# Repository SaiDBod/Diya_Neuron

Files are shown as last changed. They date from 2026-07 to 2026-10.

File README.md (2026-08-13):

# Diya
Light illumination device for cells cultured in multiwell plates or culture dishes

## hardware
- CAD files for hardware designs
- More_CAD contains files for Adafruit 64x64 P3 board and a container for the controller
- Assembly instructions

## software
- Source code for Diya GUI
- See Output Folder for Windows Installer
- Diya_Neuron_Installer is Inno Setup file for the creation of the Installer

## Advanced - Modification Descriptions
- Added this to Line 354 - 355 of mainWidget.py while changing subsequent lines:
    - self.StepGBoxes[step_nr][6].setDecimals(2)
    - self.StepGBoxes[step_nr][6].setSingleStep(0.02)
    - self.StepGBoxes[step_nr][6].setSuffix(' sec')
    - self.StepGBoxes[step_nr][6].setMaximum(59.99)
- Line 333 of mainWidget.py changed to:  QSpinBox(), QSpinBox(), QDoubleSpinBox(),
- framerate (limiting factor) on line 47 of setup.py was changed to 1/3000 for 20 ms times
- Line 401 of makegif.py changed from fps=10 to fps=50 (20 ms times)

## Other Notes
- The exported GIFs only make frames every 20 ms, so steps at 0.01, 0.03, 0.05... seconds may not work as intended
- 10 ms frame times do not work with HUIDU technology/ software (hard limit seems to be at 60 FPS, but only 50 FPS was tested)

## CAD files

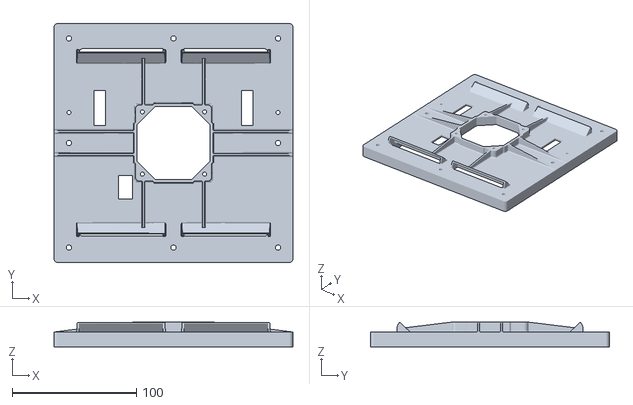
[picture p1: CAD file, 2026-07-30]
hardware/CAD_files/back_plate/back_plate_complete.stl
192.0 x 192.0 x 20.0

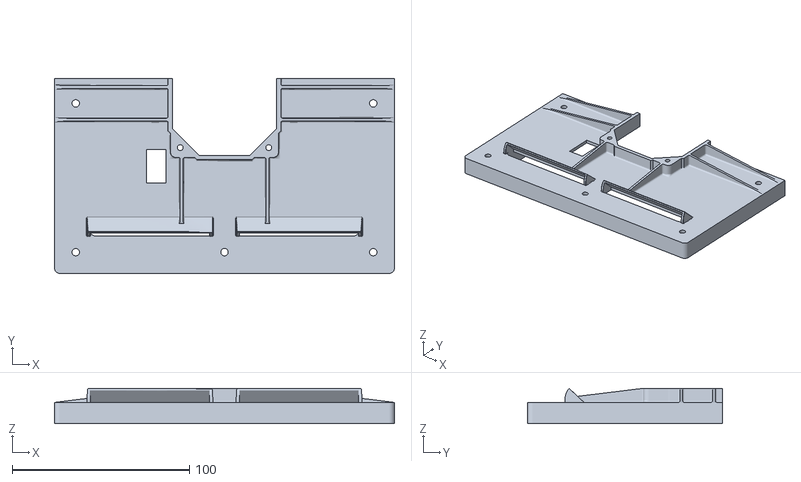
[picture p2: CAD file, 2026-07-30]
hardware/CAD_files/back_plate/back_plate_part2.stl
192.0 x 110.0 x 20.0

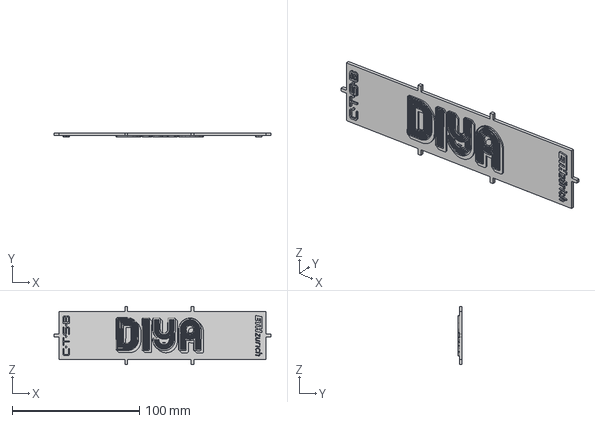
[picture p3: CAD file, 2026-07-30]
hardware/CAD_files/diya_logo/diya_ctsb_eth_logo.step
170.6 x 3.00 x 45.6 mm

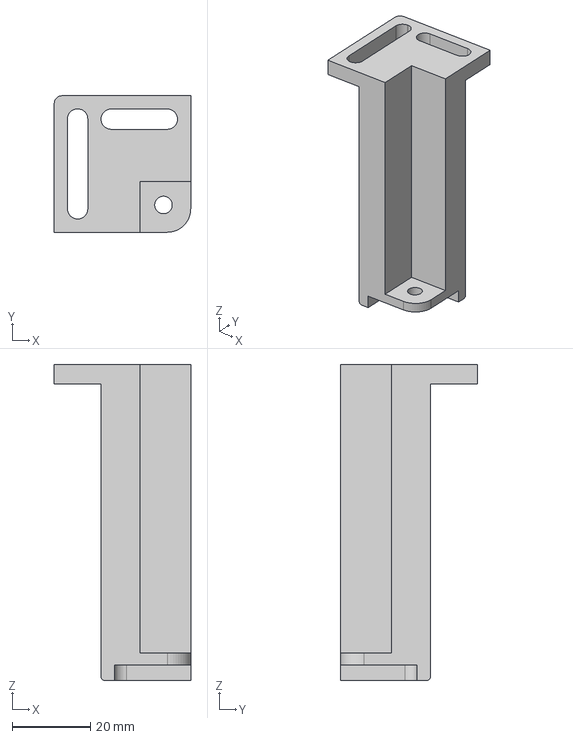
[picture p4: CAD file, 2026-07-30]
hardware/CAD_files/stands/stands.step
35.0 x 35.0 x 81.0 mm

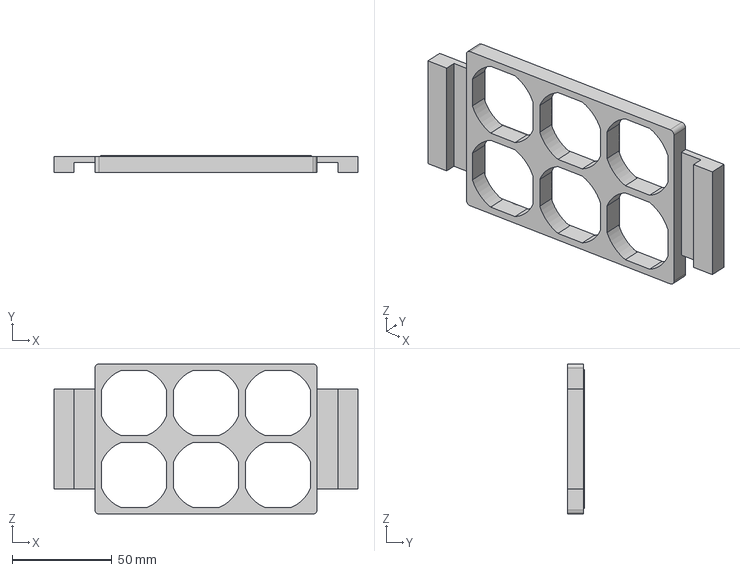
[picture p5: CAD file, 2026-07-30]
hardware/CAD_files/well_plate_adapters/6_well_plate_adapter.step
152.0 x 8.50 x 75.0 mm

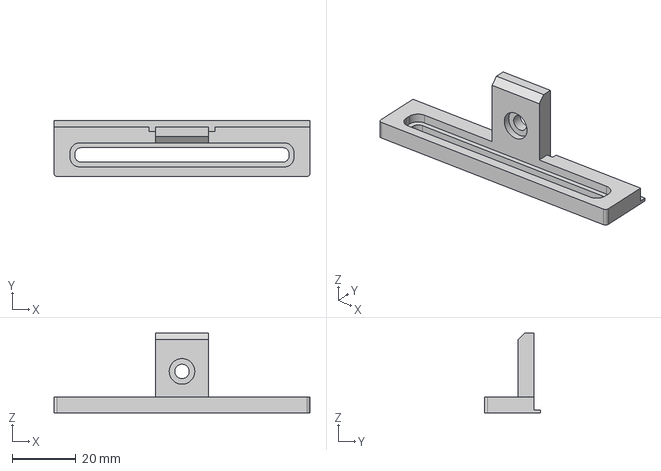
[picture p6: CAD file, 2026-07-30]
hardware/CAD_files/well_plate_clamper/side_clamps.step
80.0 x 17.5 x 25.0 mm

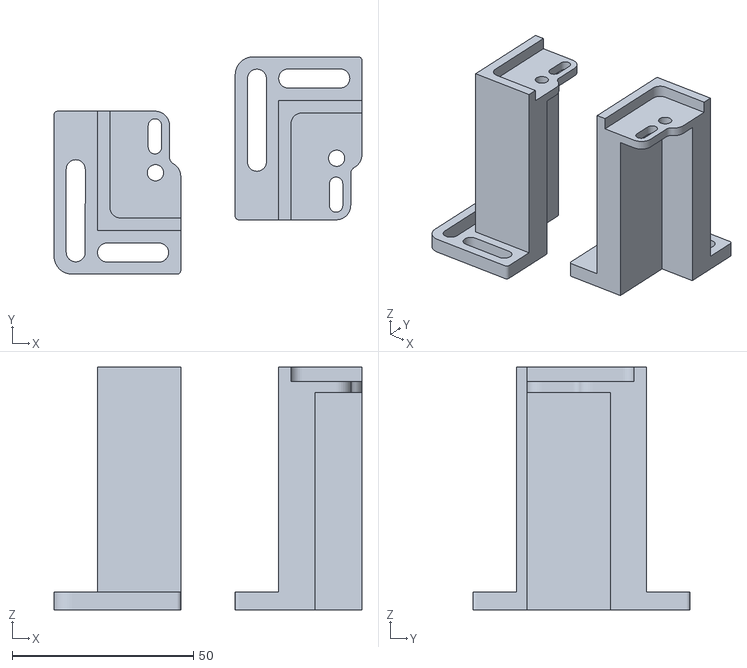
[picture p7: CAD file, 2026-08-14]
More_CAD/Stands_ReImagined2.stl
85.0 x 60.0 x 67.0

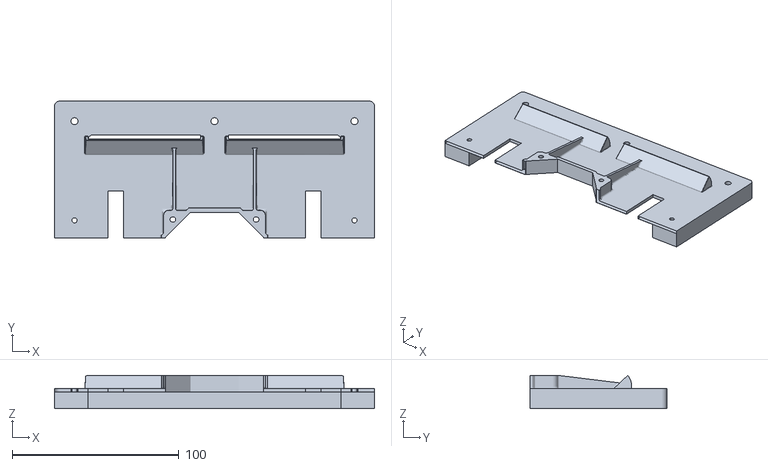
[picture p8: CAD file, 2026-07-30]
hardware/CAD_files/back_plate/back_plate_part1.stl
192.0 x 82.0 x 20.0

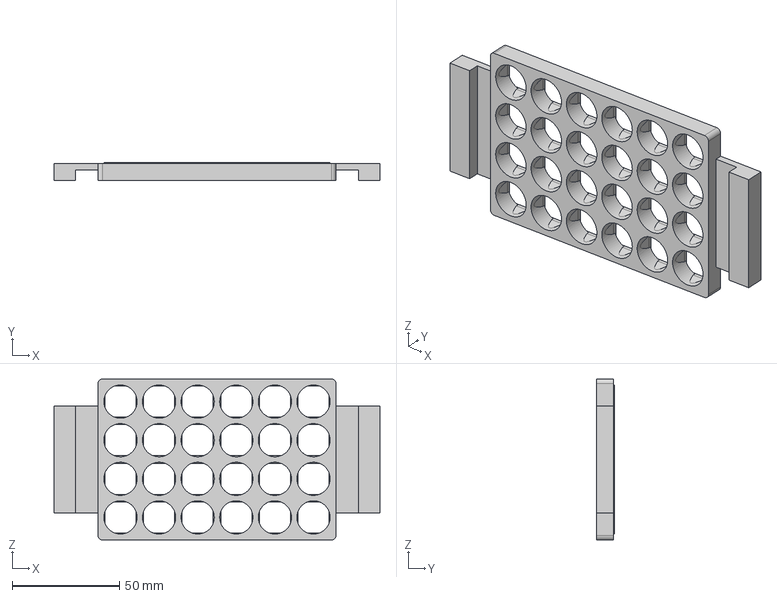
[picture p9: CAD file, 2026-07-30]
hardware/CAD_files/well_plate_adapters/24_well_plate_adapter.step
152.0 x 8.50 x 75.0 mm

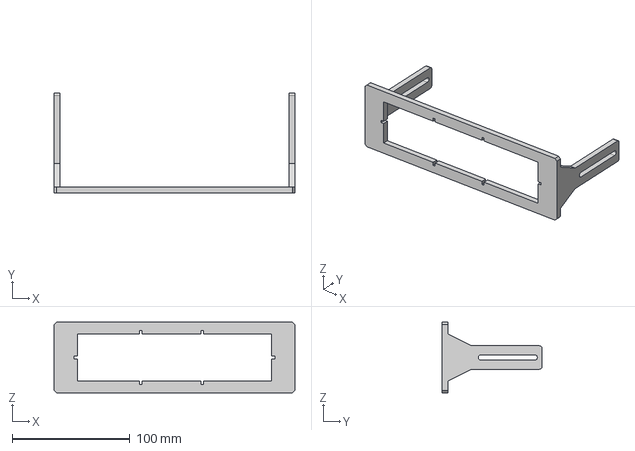
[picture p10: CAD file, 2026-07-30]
hardware/CAD_files/well_plate_clamper/well_plate_clamper.step
205.0 x 85.0 x 60.0 mm

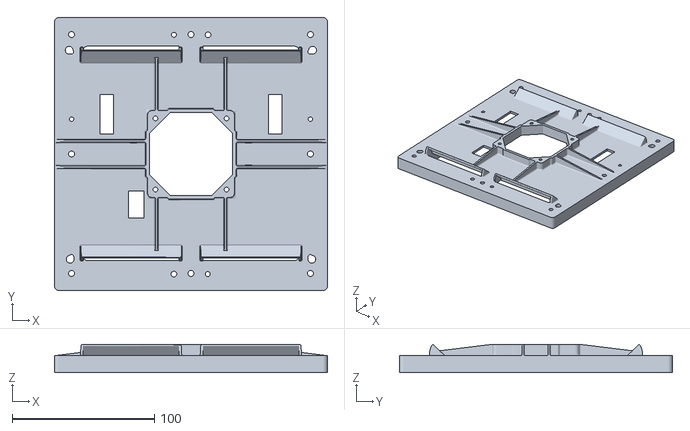
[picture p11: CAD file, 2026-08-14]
More_CAD/BackPlate_ReImagined5.stl
192.0 x 192.0 x 20.0

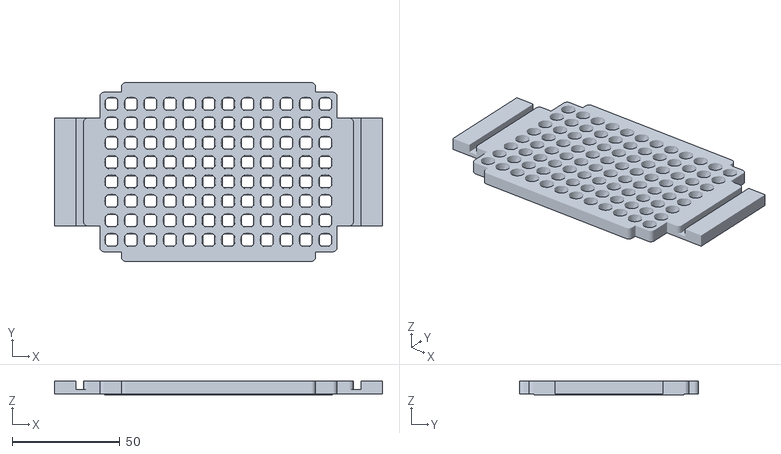
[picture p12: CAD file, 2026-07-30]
hardware/CAD_files/well_plate_adapters/96_U_bottom_adapter.stl
152.0 x 82.9 x 6.50

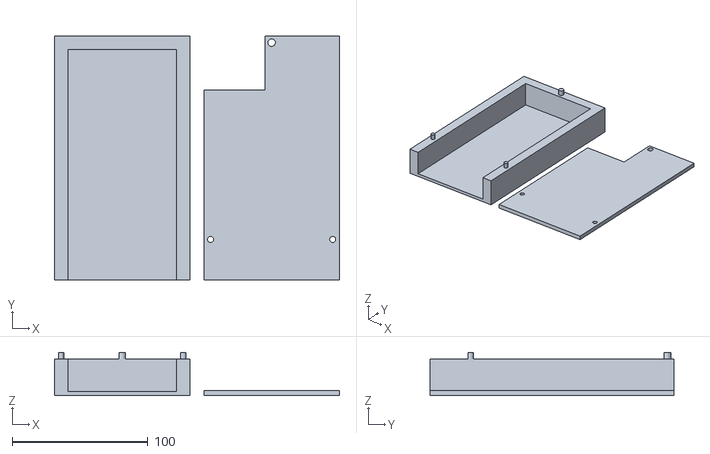
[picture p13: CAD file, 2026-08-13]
More_CAD/Huidu_Holder2.stl
210.0 x 180.0 x 32.0

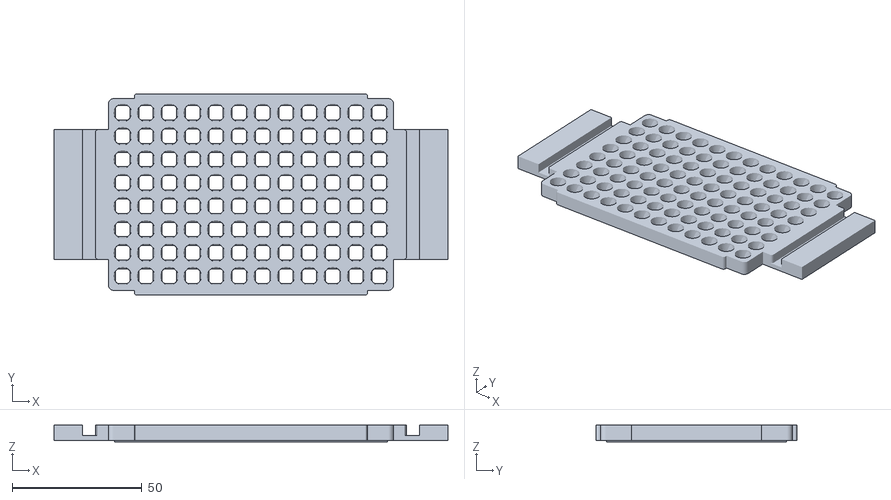
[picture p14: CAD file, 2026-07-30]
hardware/CAD_files/well_plate_adapters/96_well_plate_adapter.stl
152.0 x 77.6 x 6.50

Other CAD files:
hardware/CAD_files/diya_logo/diya_ctsb_eth_logo.stl
hardware/CAD_files/stands/stands.stl
hardware/CAD_files/well_plate_adapters/24_well_plate_adapter.stl
hardware/CAD_files/well_plate_adapters/6_well_plate_adapter.stl
hardware/CAD_files/well_plate_clamper/side_clamps.stl
hardware/CAD_files/well_plate_clamper/well_plate_clamper.stl

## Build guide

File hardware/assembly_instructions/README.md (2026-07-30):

This pdf contains step-by-step intructions for assembling a Diya device. The instructions assume that you have acquired and 3D printed all the parts needed for the assembly. Please refer to the paper for more details.

* Parts list is provided in the paper supplimentary information.
* CAD files for 3D printing are available in the hardware > CAD_files folder (in this repository).

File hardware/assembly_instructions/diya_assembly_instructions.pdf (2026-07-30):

## Step 0

- Acquire all parts (check parts list provided in the paper supplementary information) needed for assembling one Diya device
- Print the required 3D printed parts (check hardware > CAD_files folder)
- A set of screw drivers is needed in the assembly process

## Step 1

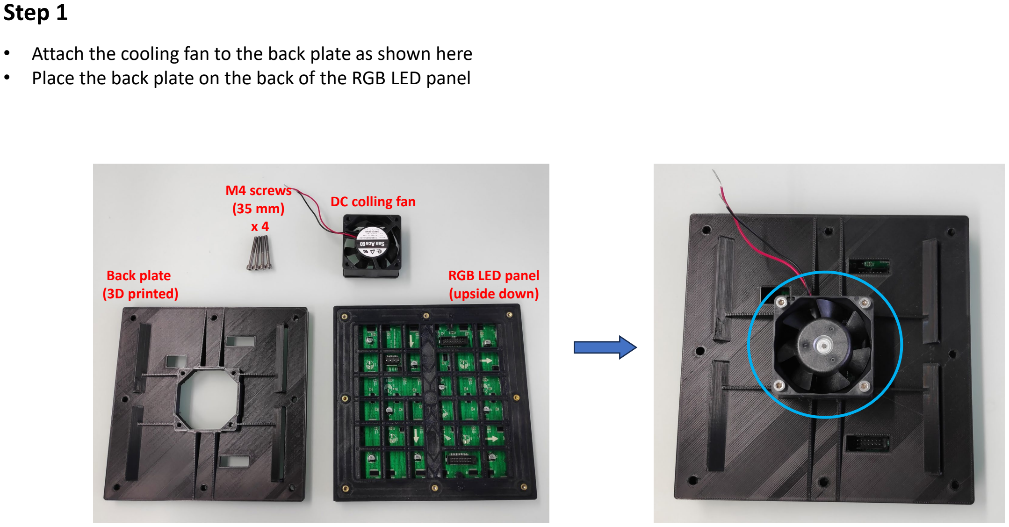
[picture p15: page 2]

- Attach the cooling fan to the back plate as shown here
- Place the back plate on the back of the RGB LED panel

Back plate
(3D printed)

RGB LED panel
(upside down)

M4 screws
(35 mm)
x 4

DC colling fan

## Step 2

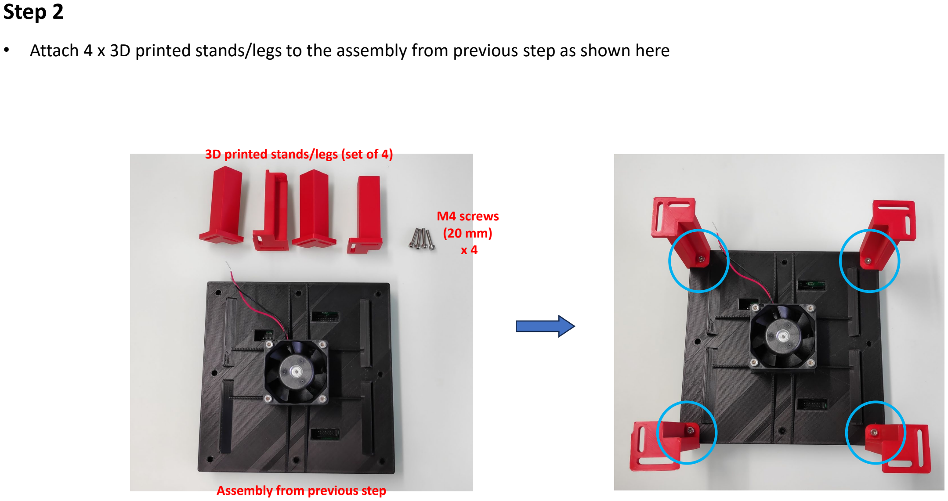
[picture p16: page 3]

- Attach 4 x 3D printed stands/legs to the assembly from previous step as shown here

Assembly from previous step

3D printed stands/legs (set of 4)

M4 screws
(20 mm)
x 4

## Step 3

- Attach 2 x 3D printed side clamps to the assembly from previous step as shown here

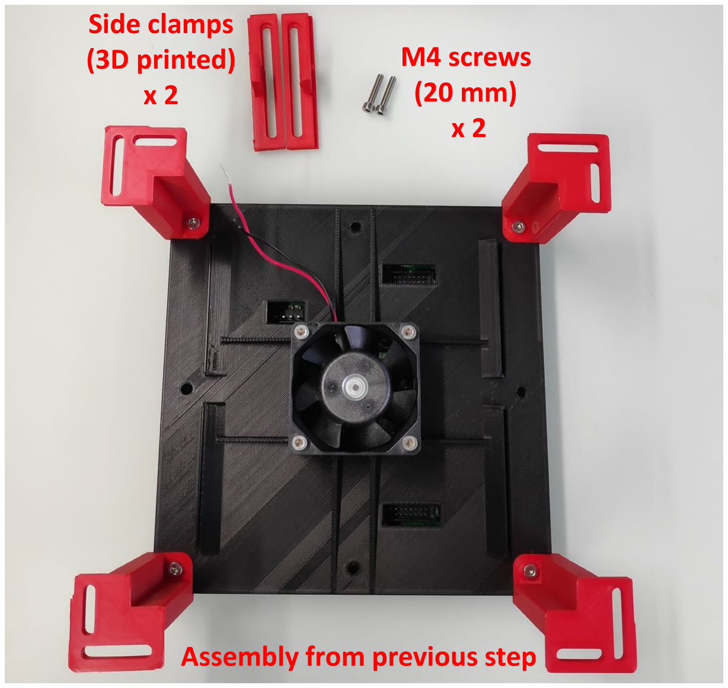
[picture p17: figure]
Assembly from previous step; Side clamps (3D printed) x 2; M4 screws (20 mm) x 2
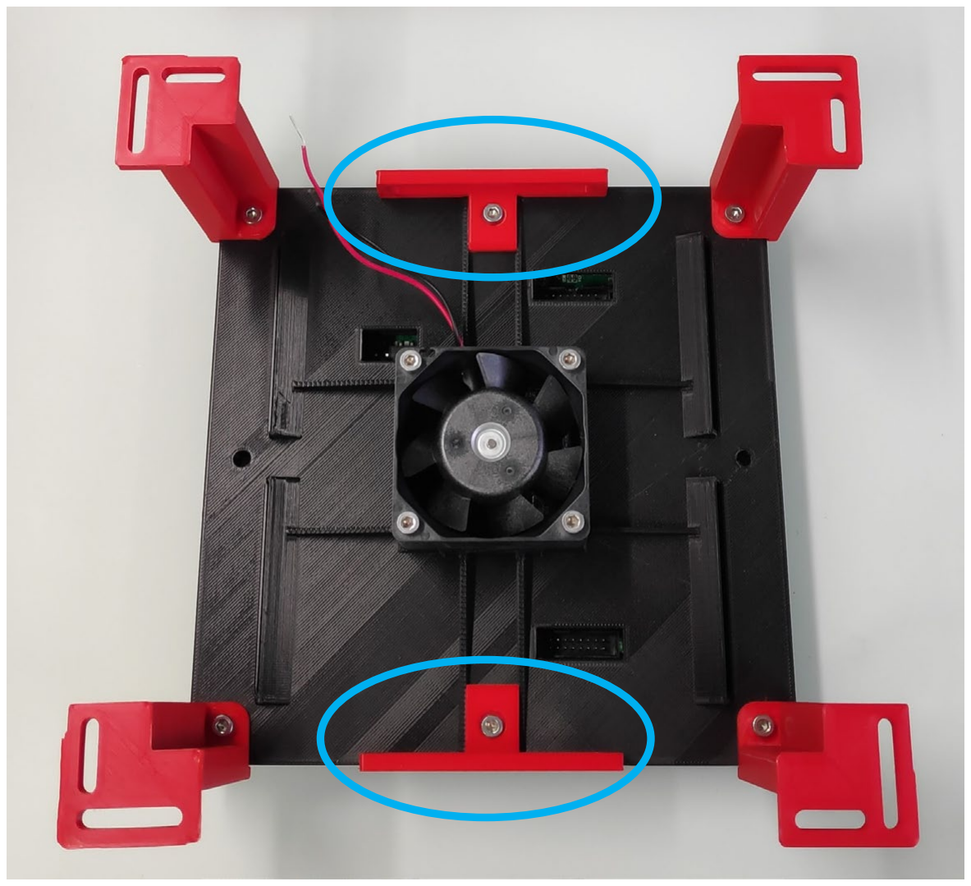
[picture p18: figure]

## Step 4

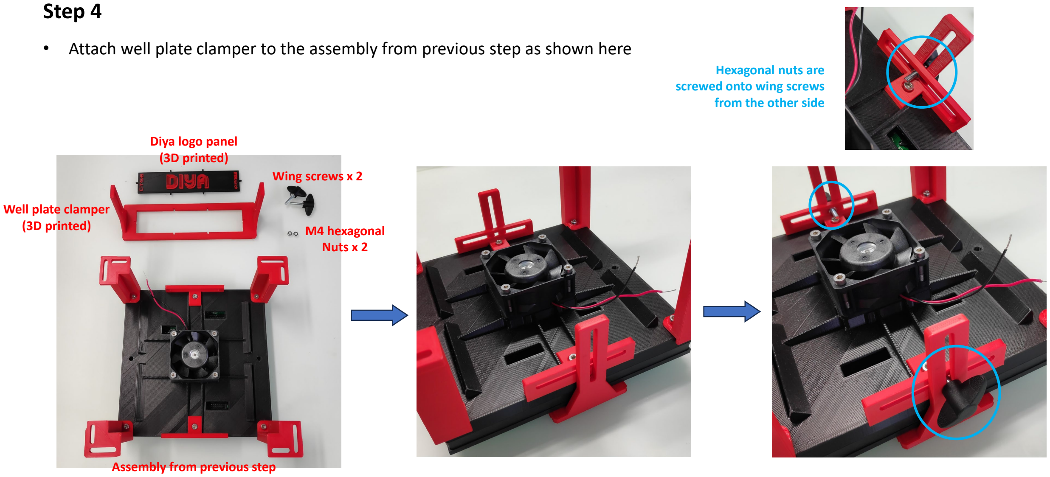
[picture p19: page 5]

- Attach well plate clamper to the assembly from previous step as shown here

Assembly from previous step

Well plate clamper
(3D printed)

Diya logo panel
(3D printed)
Wing screws x 2

M4 hexagonal
Nuts x 2

Hexagonal nuts are
screwed onto wing screws
from the other side

## Step 5 (Optional)

- Attach Diya logo panel to the well plate clamper as shown here
- Glue can be used to firmly attach the logo panel in place

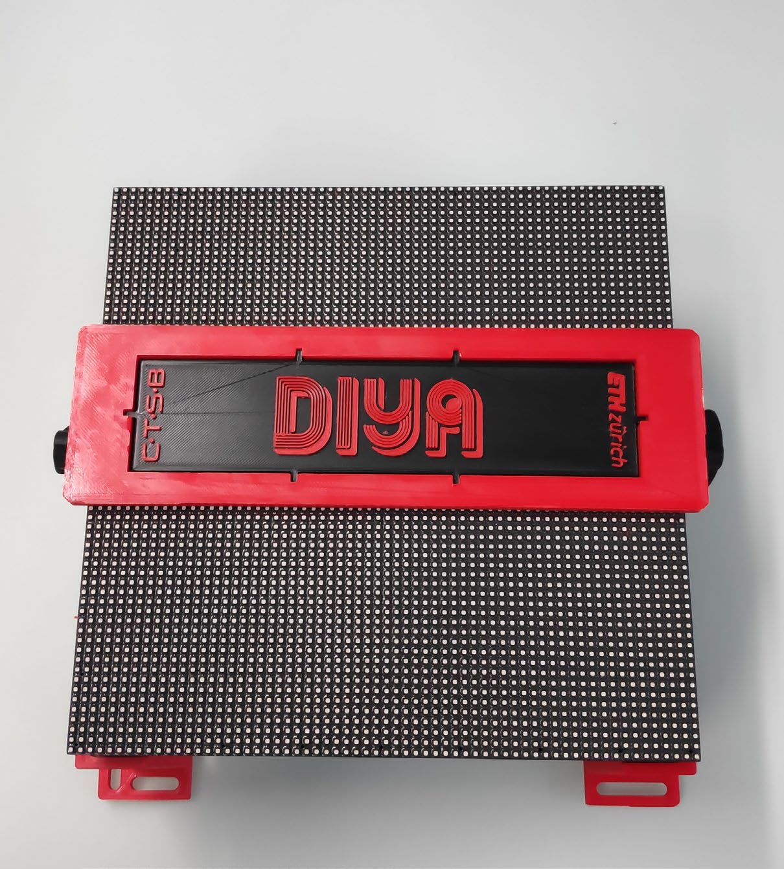
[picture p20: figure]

## Step 6

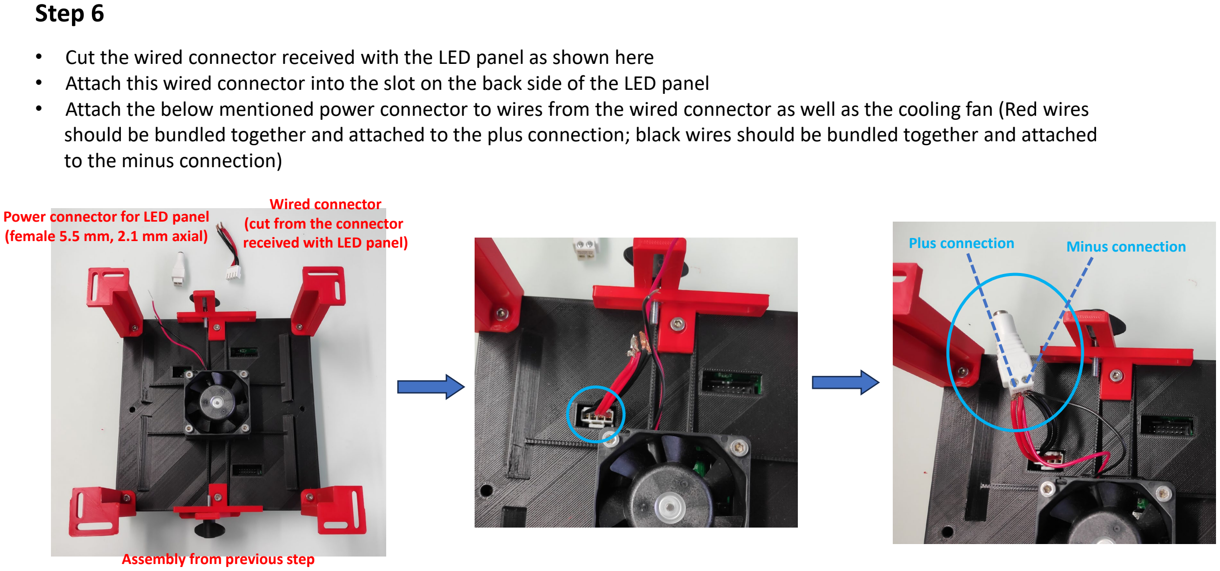
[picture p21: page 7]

- Cut the wired connector received with the LED panel as shown here
- Attach this wired connector into the slot on the back side of the LED panel
- Attach the below mentioned power connector to wires from the wired connector as well as the cooling fan (Red wires should be bundled together and attached to the plus connection; black wires should be bundled together and attached to the minus connection)

Assembly from previous step

Power connector for LED panel (female 5.5 mm, 2.1 mm axial)

Wired connector
(cut from the connector
received with LED panel) | Plus connection | Minus connection

## Step 7

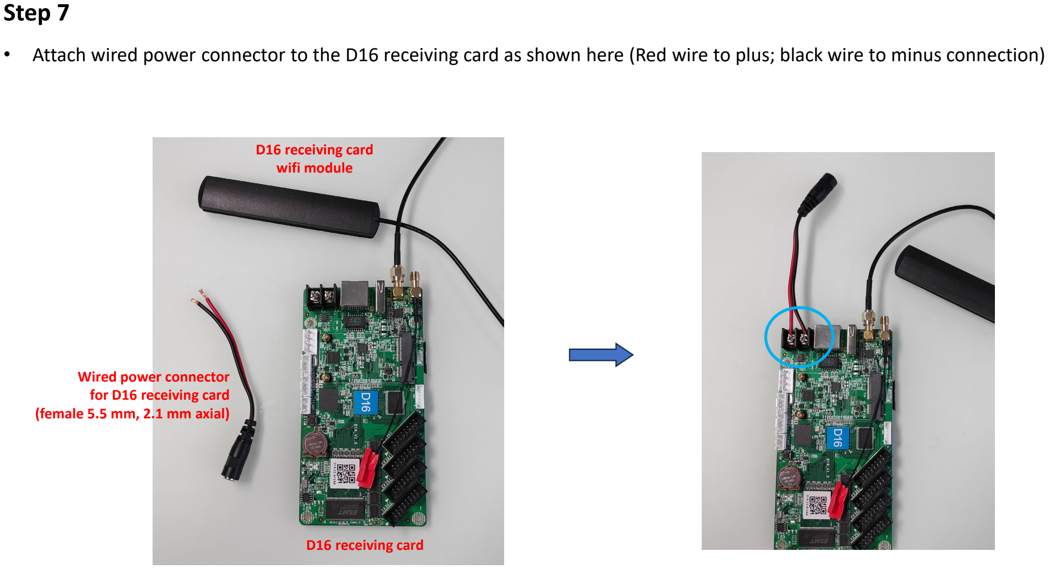
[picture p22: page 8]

- Attach wired power connector to the D16 receiving card as shown here (Red wire to plus; black wire to minus connection)

Wired power connector
for D16 receiving card
(female 5.5 mm, 2.1 mm axial)

D16 receiving card
wifi module

D16 receiving card

## Step 8

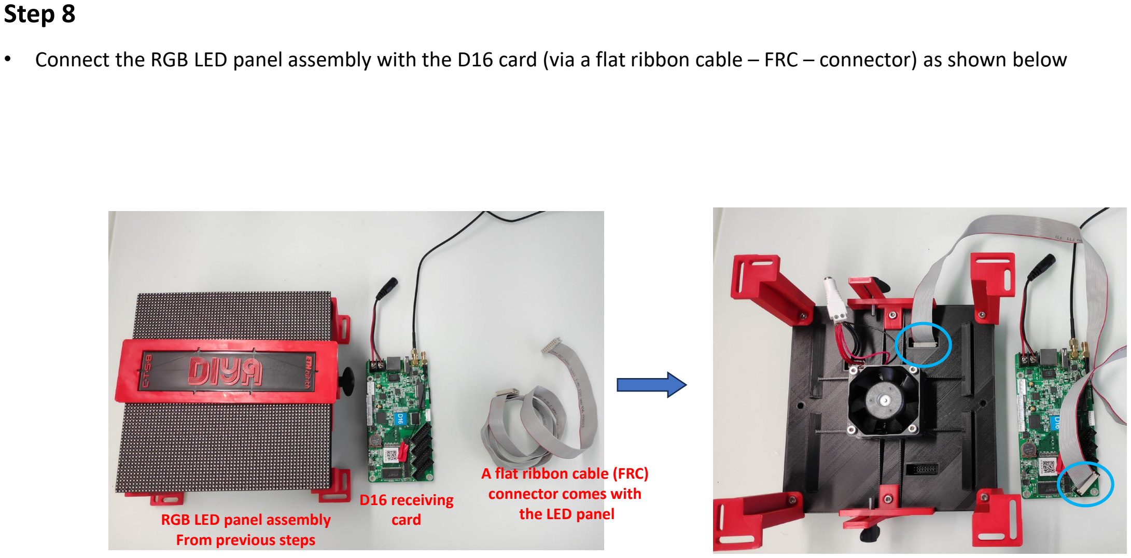
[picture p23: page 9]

- Connect the RGB LED panel assembly with the D16 card (via a flat ribbon cable – FRC – connector) as shown below

RGB LED panel assembly
From previous steps

A flat ribbon cable (FRC)
connector comes with
the LED panel D16 receiving card

## Step 9

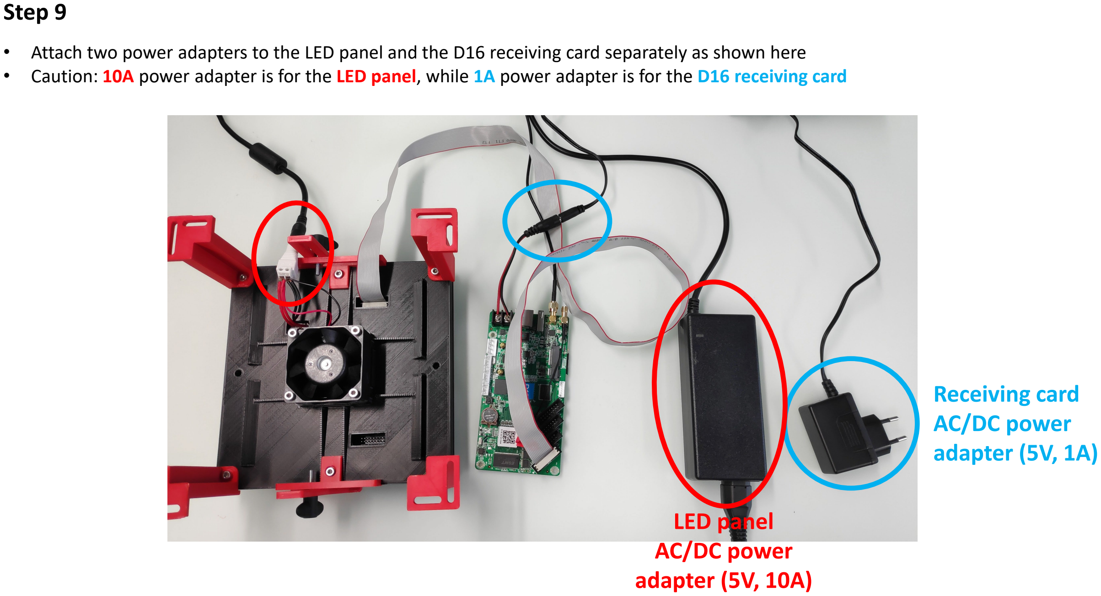
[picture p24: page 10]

- Attach two power adapters to the LED panel and the D16 receiving card separately as shown here
- Caution: 10A power adapter is for the LED panel, while 1A power adapter is for the D16 receiving card

## Receiving card AC/DC power adapter (5V, 1A)

## LED panel AC/DC power adapter (5V, 10A)

## Step 10

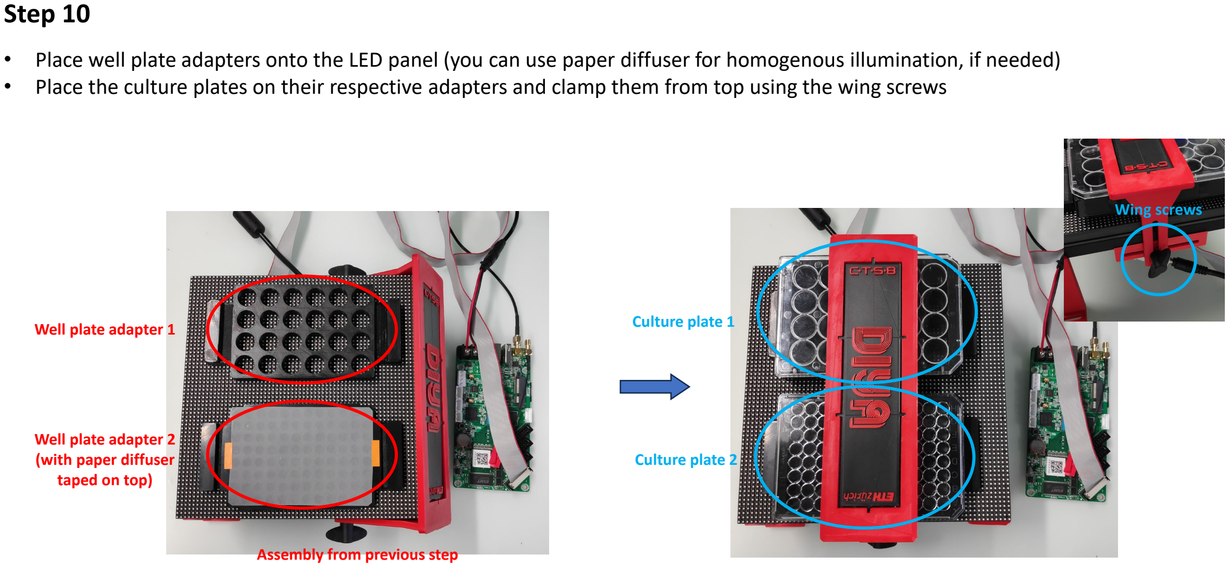
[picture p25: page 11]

- Place well plate adapters onto the LED panel (you can use paper diffuser for homogenous illumination, if needed)
- Place the culture plates on their respective adapters and clamp them from top using the wing screws

Well plate adapter 1

Well plate adapter 2
(with paper diffuser
taped on top)

Assembly from previous step

Wing screws

Culture plate 1

Culture plate 2

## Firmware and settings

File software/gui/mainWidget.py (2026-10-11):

from PyQt5.QtWidgets import *
from PyQt5.QtGui import * 
from PyQt5.QtCore import *

from pyqtgraph import PlotWidget, plot
import pyqtgraph as pg

import ast
import os

import numpy as np
from math import sqrt

from wellInforamtion import wellInfoWindow

basedir = os.path.dirname(__file__)

class well_buttons(QWidget):#
    #Creation of widgets
    def __init__(self, framerate):
        super().__init__()

        self.plate_type = 96
        self.plate_nr = 0

        self.plate_nr_type = {0: 96, 1: 96}

        self.plate_width = 8
        self.plate_height = 12
        self.well_button_size = 30
        self.well_button_radius = 15

        self.color = 'Off'
        self.wvMax = 255
        self.wvMin = 0
        self.wvStart = 'Low'
        self.wvLen = 20
        self.dutyCyclePWM = 0.5
        self.periodPWM = 20

        self.framerate = framerate

        self.StepGBoxes = {}
        self.StepInformations = {}
        self.amount_of_steps = 1
        self.selceted_step = 1

        self.ButtonNrTL = 1
        self.selected_wells = set()
        self.used_wells_plate_1 = {}
        self.used_wells_plate_2 = {}
        self.Button_to_pos = {}
        self.Pos_to_Button = {}

        self.plotPreviewDisplayed = False
        self.wellInfoWin = None
        
        self.setWindowTitle('opto GUI')
        self.createPlotPreview(10)
        self.createPlateChooserBox()
        self.createCurrentStepBox()
        self.createProgrammBox()
        self.createActions()
        self.createContextMenu()
        
        self.selectWellsRB.setChecked(True)

        self.graphProgrammStack = QStackedWidget(self)
        self.graphProgrammStack.addWidget(self.ProgrammGBox)
        self.graphProgrammStack.addWidget(self.graphWidget)

        Programm_HLayout = QVBoxLayout()
        Programm_HLayout.addWidget(self.PlateChooserBox)
        Programm_HLayout.addWidget(self.graphProgrammStack)

        self.mainLayout = QHBoxLayout()
        self.mainLayout.addLayout(Programm_HLayout)
        self.mainLayout.addWidget(self.CurrentStepGBox)
        self.setLayout(self.mainLayout)

    def createwellButtonBox(self):

        self.wellButtonBox = QGroupBox("Select wells")
        wells_layout = QGridLayout()

        rows_per_plate, cols_per_plate = self.plate_height, self.plate_width

        self.select_buttons = {}
        self.well_buttons = {}
        self.Button_to_pos = {}
        self.Pos_to_Button = {}

        self.select_all_button = QPushButton('All', self)
        self.select_all_button.\
         setStyleSheet("border-radius : {radius}; border: 1px solid black;".format(radius = 15))
        self.select_all_button.setFixedSize(30, 30)
        self.select_all_button.clicked.connect(self.select_all)
        wells_layout.addWidget(self.select_all_button, 0, 0, alignment = Qt.AlignCenter)

        for col in range(cols_per_plate):
            col_nr = col + 1
            self.select_buttons['Button_C' + str(col_nr)] = QPushButton('', self)
            self.select_buttons['Button_C' + str(col_nr)].\
             setStyleSheet("border-radius : {radius}; border: 1px solid black;".format(radius = 15))
            self.select_buttons['Button_C' + str(col_nr)].setIcon(QIcon(os.path.join(basedir, 'resources', 'arrow-down.svg')))
            self.select_buttons['Button_C' + str(col_nr)].setFixedSize(30, 30)
            self.select_buttons['Button_C' + str(col_nr)].clicked.connect(lambda ignore, i=col_nr: self.select_col(i))
            wells_layout.addWidget(self.select_buttons['Button_C' + str(col_nr)], 0, col + 1, alignment = Qt.AlignCenter)

        for row in range(rows_per_plate):
            row_nr = row + 1
            self.select_buttons['Button_R' + str(row_nr)] = QPushButton('', self)
            self.select_buttons['Button_R' + str(row_nr)].\
             setStyleSheet("border-radius : {radius}; border: 1px solid black;".format(radius = 15))
            self.select_buttons['Button_R' + str(row_nr)].setIcon(QIcon(os.path.join(basedir, 'resources', 'arrow-right.svg')))
            self.select_buttons['Button_R' + str(row_nr)].setFixedSize(30, 30)
            self.select_buttons['Button_R' + str(row_nr)].clicked.connect(lambda ignore, i=row_nr: self.select_row(i))
            wells_layout.addWidget(self.select_buttons['Button_R' + str(row_nr)], row + 1, 0, alignment = Qt.AlignCenter)

        for x in range(cols_per_plate):
            for y in range(rows_per_plate):
                button_nr = x+y*cols_per_plate+1
                self.well_buttons['Button_' + str(button_nr)] = QPushButton('', self)
                self.Button_to_pos['Button_' + str(button_nr)] = (y, x)
                self.well_buttons['Button_' + str(button_nr)].\
                 setStyleSheet("border-radius : {radius}; border: 1px solid black;".format(radius = self.well_button_radius))
                self.well_buttons['Button_' + str(button_nr)].setFixedSize(self.well_button_size, self.well_button_size)
                self.well_buttons['Button_' + str(button_nr)].clicked.connect(lambda ignore, i=button_nr: self.select_wells(i))
                self.well_buttons['Button_' + str(button_nr)].setContextMenuPolicy(Qt.CustomContextMenu)
                self.well_buttons['Button_' + str(button_nr)].customContextMenuRequested.connect(lambda point, i=button_nr: self.showWellContextMenu(i, point))
                wells_layout.addWidget(self.well_buttons['Button_' + str(button_nr)], y+1, x+1)
        self.wellButtonBox.setLayout(wells_layout)
        self.Pos_to_Button = {y: x for x, y in self.Button_to_pos.items()}

    def createPlateChooserBox(self):
        self.PlateChooserBox = QGroupBox("Choose Plate")
        chooserForm_layout = QFormLayout()

        self.plate_chooser_CB = QComboBox()
        self.plate_chooser_CB.addItem("Plate 1")
        self.plate_chooser_CB.addItem("Plate 2")
        self.plate_chooser_CB.addItem("---")

        self.plate_chooser_CBView = self.plate_chooser_CB.view()
        self.plate_chooser_CBView.setRowHidden(2, True)

        self.plate_chooser_CB.currentIndexChanged.connect(self.changePlate)

        self.plate_type_CB = QComboBox()
        self.plate_type_CB.addItem("96-well Plate")
        self.plate_type_CB.addItem("24-well Plate")
        self.plate_type_CB.addItem("6-well Plate")
        self.plate_type_CB.addItem("Custom Shape")

        self.plate_type_CBView = self.plate_type_CB.view()
        self.plate_type_CBView.setRowHidden(3, True)

        self.plate_type_CB.currentIndexChanged.connect(self.changePlateType)

        self.duplicate_plate_button = QPushButton('Duplicate Plate', self)
        self.duplicate_plate_button.clicked.connect(self.duplicate_plate)

        chooserForm_layout.addRow(QLabel('Choose Plate'), self.plate_chooser_CB)
        chooserForm_layout.addRow(QLabel('Choose Plate Type'), self.plate_type_CB)
        chooserForm_layout.addRow(QLabel(''), self.duplicate_plate_button)

        self.PlateChooserBox.setLayout(chooserForm_layout)

    def createParameterBox(self):
        self.ParameterBox = QGroupBox("Animate wells")
        self.ParameterFormlayout = QFormLayout()

        self.color_chooser = QComboBox()
        self.color_chooser.addItem("Off")
        self.color_chooser.addItem("Red")
        self.color_chooser.addItem("Green")
        self.color_chooser.addItem("Blue")
        self.color_chooser.addItem("Multicolor")
        self.color_chooser.setCurrentText(self.color)
        self.color_chooser.currentIndexChanged.connect(self.changeWavetype)

        self.waveTypeCB = QComboBox()
        self.waveTypeCB.addItem("Constant")
        self.waveTypeCB.addItem("Sine Wave")
        self.waveTypeCB.addItem("Tri Wave")
        self.waveTypeCB.addItem("Square Wave")
        self.waveTypeCB.addItem("PWM")
        self.waveTypeCB.addItem("Rise")
        self.waveTypeCB.addItem("Fall")
        self.waveTypeCB.setItemIcon(0, QIcon(os.path.join(basedir, 'resources', 'animation-static.svg')))
        self.waveTypeCB.setItemIcon(1, QIcon(os.path.join(basedir, 'resources', 'animation-sin.svg')))
        self.waveTypeCB.setItemIcon(2, QIcon(os.path.join(basedir, 'resources', 'animation-tri.svg')))
        self.waveTypeCB.setItemIcon(3, QIcon(os.path.join(basedir, 'resources', 'animation-sq.svg')))
        self.waveTypeCB.setItemIcon(4, QIcon(os.path.join(basedir, 'resources', 'animation-blink.svg')))
        self.waveTypeCB.setItemIcon(5, QIcon(os.path.join(basedir, 'resources', 'animation-rise.svg')))
        self.waveTypeCB.setItemIcon(6, QIcon(os.path.join(basedir, 'resources', 'animation-fall.svg')))
        self.waveTypeCB.currentIndexChanged.connect(self.changeWavetype)

        self.ParameterFormlayout.addRow(QLabel('Color: '), self.color_chooser)
        self.ParameterFormlayout.addRow(QLabel('Type: '), self.waveTypeCB)

        self.ParameterBox.setLayout(self.ParameterFormlayout)

        self.changeWavetype()

    def updateGradientRGBVisibility(self, color):
        self.rgb_gradient_widget.setVisible(color == "Multicolor")
    
    def createGradientDesingerBox(self):
        self.GradientBox = QGroupBox("Gradient")
        gradientForm_layout = QFormLayout()
        gradientSize_layout = QHBoxLayout()

        self.color_chooser_gradient = QComboBox()
        self.color_chooser_gradient.addItem("Red")
        self.color_chooser_gradient.addItem("Green")
        self.color_chooser_gradient.addItem("Blue")
        self.color_chooser_gradient.addItem("Multicolor")

        
        # RGB controls for the Multicolor gradient
        self.red_gradient = QSpinBox()
        self.red_gradient.setRange(0, 255)
        self.red_gradient.setValue(0)

        self.green_gradient = QSpinBox()
        self.green_gradient.setRange(0, 255)
        self.green_gradient.setValue(0)

        self.blue_gradient = QSpinBox()
        self.blue_gradient.setRange(0, 255)
        self.blue_gradient.setValue(255)

        self.color_chooser_gradient.currentTextChanged.connect(
            self.updateGradientRGBVisibility
        )

        
        self.width_gradient = QSpinBox()
        self.width_gradient.setMaximum(self.plate_width)
        self.width_gradient.setMinimum(2)
        self.width_gradient.setValue(8)
        self.width_gradient.valueChanged.connect(lambda: self.select_wells(self.ButtonNrTL))
        self.height_gradient = QSpinBox()
        self.height_gradient.setMaximum(self.plate_height)
        self.height_gradient.setMinimum(2)
        self.height_gradient.setValue(12)
        self.height_gradient.valueChanged.connect(lambda: self.select_wells(self.ButtonNrTL))
        gradientSize_layout.addWidget(self.width_gradient)
        gradientSize_layout.addWidget(QLabel("x"))
        gradientSize_layout.addWidget(self.height_gradient)

        self.direction_chooser_gradient = QComboBox()
        self.direction_chooser_gradient.addItem("Top --> Bottom")
        self.direction_chooser_gradient.addItem("Bottom --> Top")
        self.direction_chooser_gradient.addItem("Left --> Right")
        self.direction_chooser_gradient.addItem("Right --> Left")

        self.max_gradient = QSpinBox()
        self.max_gradient.setMaximum(255)
        self.max_gradient.setValue(255)
        self.min_gradient = QSpinBox()
        self.min_gradient.setMaximum(254)
        self.min_gradient.valueChanged.connect(lambda x: self.max_gradient.setMinimum(self.min_gradient.value() + 1))
        self.max_gradient.valueChanged.connect(lambda x: self.min_gradient.setMaximum(self.max_gradient.value() - 1))

        gradientForm_layout.addRow(QLabel('Color'), self.color_chooser_gradient)
        gradientForm_layout.addRow(QLabel('Size'), gradientSize_layout)
        gradientForm_layout.addRow(QLabel('Direction'), self.direction_chooser_gradient)
        gradientForm_layout.addRow(QLabel('Min. intensity'), self.min_gradient)
        gradientForm_layout.addRow(QLabel('Max. intensity'), self.max_gradient)

        self.apply_button_gradient = QPushButton('Apply', self)
        self.apply_button_gradient.clicked.connect(self.createGradient)
        self.apply_button_gradient.setDefault(True)
        gradientForm_layout.addRow(QLabel(), self.apply_button_gradient)

        #extra controls for gradient (multicolor)
        # gradientForm_layout.addRow(QLabel('Red (0-255)'), self.red_gradient)
        # gradientForm_layout.addRow(QLabel('Green (0-255)'), self.green_gradient)
        # gradientForm_layout.addRow(QLabel('Blue (0-255)'), self.blue_gradient)

        self.rgb_gradient_layout = QVBoxLayout()

        self.rgb_gradient_layout.addWidget(QLabel("Red (0-255)"))
        self.rgb_gradient_layout.addWidget(self.red_gradient)

        self.rgb_gradient_layout.addWidget(QLabel("Green (0-255)"))
        self.rgb_gradient_layout.addWidget(self.green_gradient)

        self.rgb_gradient_layout.addWidget(QLabel("Blue (0-255)"))
        self.rgb_gradient_layout.addWidget(self.blue_gradient)

        self.rgb_gradient_widget = QWidget()
        self.rgb_gradient_widget.setLayout(self.rgb_gradient_layout)

        gradientForm_layout.addRow(QLabel("RGB Color"), self.rgb_gradient_widget)
        self.updateGradientRGBVisibility(self.color_chooser_gradient.currentText())

        self.GradientBox.setLayout(gradientForm_layout)

    def createPlotPreview(self, stepLength):
        self.graphWidget = pg.PlotWidget()
        self.pen = pg.mkPen(color='red', width=2)

        self.graphWidget.setBackground('w')
        self.graphWidget.setLimits(xMin = 0, xMax = stepLength - self.framerate + (stepLength - self.framerate) * 0.05, yMin = -1, yMax = 256, minXRange = 0.001, minYRange = 1)
        labelStyle = {'color': 'black', 'font-size': '12pt'}
        self.graphWidget.setLabel('bottom', "Time / min", **labelStyle)
        self.graphWidget.setLabel('left', "Intensity", **labelStyle)
        self.graphWidget.setXRange(0, stepLength - self.framerate + (stepLength - self.framerate) * 0.05)
        self.graphWidget.setYRange(0, 260)

        self.data_line =  self.graphWidget.plot([0], [0], pen=self.pen)


    def createCurrentStepBox(self):
        self.CurrentStepGBox = QGroupBox("Step 1")
        self.CurrentStepGBox_Layout = QHBoxLayout()
        Parameter_Layout = QVBoxLayout()
        Preview_select_Layout = QVBoxLayout()

        rb_layout = QHBoxLayout()
        self.selectWellsRB = QRadioButton("Select wells")
        self.selectWellsRB.toggled.connect(lambda: self.changeSelectionType(0))
        rb_layout.addWidget(self.selectWellsRB)
        self.getSettingsRB = QRadioButton("Get Settings")
        self.getSettingsRB.toggled.connect(lambda: self.changeSelectionType(2))
        rb_layout.addWidget(self.getSettingsRB)
        self.createGradientRB = QRadioButton("Create gradient")
        self.createGradientRB.toggled.connect(lambda: self.changeSelectionType(1))
        rb_layout.addWidget(self.createGradientRB)

        self.createwellButtonBox()
        self.createParameterBox()
        self.createGradientDesingerBox()
        
        Parameter_Layout.addLayout(rb_layout)
        Parameter_Layout.addWidget(self.ParameterBox)
        Parameter_Layout.addWidget(self.GradientBox)

        Preview_select_Layout.addStretch()
        Preview_select_Layout.addWidget(self.wellButtonBox)
        Preview_select_Layout.addStretch()

        self.CurrentStepGBox_Layout.addLayout(Parameter_Layout)
        self.CurrentStepGBox_Layout.addLayout(Preview_select_Layout)

        self.CurrentStepGBox.setLayout(self.CurrentStepGBox_Layout)

    def createProgrammBox(self):
        self.ProgrammGBox = QGroupBox("Programm")
        ProgrammBox_layout = QVBoxLayout()

        self.addProgram_Button = QPushButton('Add Step', self)
        self.addProgram_Button.clicked.connect(self.addStep)

        self.scrollArea = QScrollArea()
        self.scrollArea.setWidgetResizable(True)
        self.scrollAreaWidget = QWidget()
        self.scrollAreaWidgetLayout = QVBoxLayout(self.scrollAreaWidget)
        self.scrollAreaWidgetLayout.addItem(QSpacerItem(20, 40, QSizePolicy.Minimum, QSizePolicy.Expanding))
        self.scrollArea.setWidget(self.scrollAreaWidget)
        self.scrollArea.setMinimumWidth(400)
        self.addStepBox()
        self.changeStep(1)

        ProgrammBox_layout.addWidget(self.addProgram_Button)
        ProgrammBox_layout.addWidget(self.scrollArea)
        
        self.ProgrammGBox.setLayout(ProgrammBox_layout)

    def addStepBox(self, newStep = True):
        step_nr = self.amount_of_steps
        #StepBox Dict: step_nr: step_nr(0), GroupBox(1), EditButton(2), Delete Button(3), Hour spinBox(4), Min spinBox(5), Sec SpinBox(6)
        self.StepGBoxes[step_nr] = [step_nr,
          QGroupBox('Step ' + str(self.amount_of_steps), self.scrollAreaWidget),
          QPushButton('Edit', self), 
          QPushButton('Delete', self),
          QSpinBox(), QSpinBox(), QDoubleSpinBox(),
          QPushButton('', self), 
          QPushButton('', self)]
        
        self.StepGBoxes[step_nr][2].clicked.connect(lambda ignore: self.changeStep(self.StepGBoxes[step_nr][0]))
        self.StepGBoxes[step_nr][3].clicked.connect(lambda ignore: self.deleteStep(self.StepGBoxes[step_nr][0]))

        self.StepGBoxes[step_nr][7].setStyleSheet('border: 0px solid black')
        self.StepGBoxes[step_nr][7].setIcon(QIcon(os.path.join(basedir, 'resources', 'arrow-up.svg')))
        self.StepGBoxes[step_nr][8].setStyleSheet('border: 0px solid black')
        self.StepGBoxes[step_nr][8].setIcon(QIcon(os.path.join(basedir, 'resources', 'arrow-down.svg')))

        self.StepGBoxes[step_nr][7].clicked.connect(lambda ignore: self.moveStepUp(self.StepGBoxes[step_nr][0]))
        self.StepGBoxes[step_nr][8].clicked.connect(lambda ignore: self.moveStepDown(self.StepGBoxes[step_nr][0]))

        self.StepGBoxes[step_nr][4].setSuffix(' h')
        self.StepGBoxes[step_nr][4].valueChanged.connect(lambda ignore: self.updateDuration_info(self.StepGBoxes[step_nr][0]))
        self.StepGBoxes[step_nr][5].setSuffix(' min')
        self.StepGBoxes[step_nr][5].setMaximum(59)
        self.StepGBoxes[step_nr][5].setValue(10)
        self.StepGBoxes[step_nr][5].valueChanged.connect(lambda ignore: self.updateDuration_info(self.StepGBoxes[step_nr][0]))
        self.StepGBoxes[step_nr][6].setDecimals(2)
        self.StepGBoxes[step_nr][6].setSingleStep(0.02)
        self.StepGBoxes[step_nr][6].setSuffix(' sec')
        self.StepGBoxes[step_nr][6].setMaximum(59.99)
        self.StepGBoxes[step_nr][6].valueChanged.connect(lambda ignore: self.updateDuration_info(self.StepGBoxes[step_nr][0]))

        StepGBox_Layout = QGridLayout(self.StepGBoxes[step_nr][1])      
        StepGBox_Layout.addWidget(QLabel('Set duration'), 0, 1, 1, 1)
        StepGBox_Layout.addWidget(self.StepGBoxes[step_nr][4], 0, 2, 1, 1)
        StepGBox_Layout.addWidget(self.StepGBoxes[step_nr][5], 0, 3, 1, 1)
        StepGBox_Layout.addWidget(self.StepGBoxes[step_nr][6], 0, 4, 1, 1)
        StepGBox_Layout.addWidget(self.StepGBoxes[step_nr][2], 1, 3, 1, 1)
        StepGBox_Layout.addWidget(self.StepGBoxes[step_nr][3], 1, 4, 1, 1)
        StepGBox_Layout.addWidget(self.StepGBoxes[step_nr][7], 0, 0, 1, 1)
        StepGBox_Layout.addWidget(self.StepGBoxes[step_nr][8], 1, 0, 1, 1)

        count = self.scrollAreaWidgetLayout.count() - 1
        self.scrollAreaWidgetLayout.insertWidget(count, self.StepGBoxes[step_nr][1])

        if newStep:
            self.StepInformations[step_nr] = [[self.StepGBoxes[step_nr][4].value(), self.StepGBoxes[step_nr][5].value(), self.StepGBoxes[step_nr][6].value()],\
             {'Plate 1 Wells': {}, 'Plate 1 Type':  self.plate_nr_type[0], 'Plate 2 Wells': {}, 'Plate 2 Type': self.plate_nr_type[1]}]

    #Actions and Menus
    def createActions(self):
        self.wellInformationAction = QAction('Informations', self)
        self.wellInformationAction.triggered.connect(self.showWellInformations)
        self.wellSettingsAction = QAction('Get Settings', self)
        self.wellSettingsAction.triggered.connect(self.getWellSettings)     

    def createContextMenu(self):
        self.wellMenu = QMenu(self)
        self.wellMenu.addAction(self.wellInformationAction)
        self.wellMenu.addAction(self.wellSettingsAction)
    
    def showWellContextMenu(self, button_nr, point):
        button = 'Button_' + str(button_nr)
        self.rightClickButtonNr = button_nr
        self.wellMenu.exec_(self.well_buttons[button].mapToGlobal(point))

    # Functions
    def moveStepUp(self, step_nr):
        if step_nr > 1:
            selectedStep = self.StepInformations[step_nr].copy()
            topStep = self.StepInformations[step_nr - 1].copy()

            self.StepInformations[step_nr] = topStep
            self.StepInformations[step_nr - 1] = selectedStep

            topH = topStep[0][0]
            topM = topStep[0][1]
            topS = topStep[0][2]

            selH = selectedStep[0][0]
            selM = selectedStep[0][1]
            selS = selectedStep[0][2]

            self.StepGBoxes[step_nr][4].setValue(topH)
            self.StepGBoxes[step_nr][5].setValue(topM)
            self.StepGBoxes[step_nr][6].setValue(topS)

            self.StepGBoxes[step_nr - 1][4].setValue(selH)
            self.StepGBoxes[step_nr - 1][5].setValue(selM)
            self.StepGBoxes[step_nr - 1][6].setValue(selS)

            self.changeStep(step_nr - 1, modify_Step = True)
            
    def moveStepDown(self, step_nr):
        if step_nr < self.amount_of_steps:
            selectedStep = self.StepInformations[step_nr].copy()
            lowStep = self.StepInformations[step_nr + 1].copy()

            self.StepInformations[step_nr] = lowStep
            self.StepInformations[step_nr + 1] = selectedStep

            lowH = lowStep[0][0]
            lowM = lowStep[0][1]
            lowS = lowStep[0][2]

            selH = selectedStep[0][0]
            selM = selectedStep[0][1]
            selS = selectedStep[0][2]
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

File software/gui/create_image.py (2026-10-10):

import numpy as np
from PIL import Image

def well_pos_to_led_pos_96(well_pos, TL):
    led_pos_x = []
    led_pos_y = []
    leds_pos = []

    led_pos_y = [well_pos[1] * 3 + TL[well_pos[0]][0], well_pos[1] * 3 + TL[well_pos[0]][0] + 1]
    led_pos_x = [well_pos[2] * 3 + TL[well_pos[0]][1], well_pos[2] * 3 + TL[well_pos[0]][1] + 1]

    for x in range(2):
        led = None
        for y in range(2):
            led = (led_pos_x[x], led_pos_y[y])
            leds_pos.append(led)

    return leds_pos

def well_pos_to_led_pos_24(well_pos, TL):
    led_pos_x = []
    led_pos_y = []
    leds_pos = []

    for i in range(5):
        led_pos_temp = well_pos[1]*6+TL[well_pos[0]][0]+i
        led_pos_y.append(led_pos_temp)
    for i in range(5):
        led_pos_temp = well_pos[2]*6+TL[well_pos[0]][1]+i
        led_pos_x.append(led_pos_temp)

    for x in range(5):
        led = None
        if x == 0 or x == 4:
            for y in range(3):
                led = (led_pos_x[x], led_pos_y[y+1])
                leds_pos.append(led)
        else:
            for y in range(5):
                led = (led_pos_x[x], led_pos_y[y]) 
                leds_pos.append(led)

    return leds_pos

def well_pos_to_led_pos_6(well_pos, TL):
    led_pos_x = []
    led_pos_y = []
    leds_pos = []

    for i in range(11):
        led_pos_temp = well_pos[1]*12+TL[well_pos[0]][0]+i
        led_pos_y.append(led_pos_temp)
    for i in range(11):
        led_pos_temp = well_pos[2]*12+TL[well_pos[0]][1]+i
        led_pos_x.append(led_pos_temp)

    for x in range(11):
        led = None
        if x == 0 or x == 10:
            for y in range(5):
                led = (led_pos_x[x], led_pos_y[y+3])
                leds_pos.append(led)
        elif x == 1 or x == 9:
            for y in range(7):
                led = (led_pos_x[x], led_pos_y[y+2])
                leds_pos.append(led)
        elif x == 2 or x == 8:
            for y in range(9):
                led = (led_pos_x[x], led_pos_y[y+1])
                leds_pos.append(led)
        else:
            for y in range(11):
                led = (led_pos_x[x], led_pos_y[y]) 
                leds_pos.append(led)

    return leds_pos

def customShapeLEDpos(customShape):
    leds_pos = []

    for y in range(customShape.shape[1]):
        for x in range(customShape.shape[0]):
            if customShape[y][x] != 0:
                leds_pos.append((x, y))

    return leds_pos


def getAnimationColors(waveType, color, stepLength, framerate, wvMax, wvMin = None, wvStart = None, wvLen = None, dutyCyclePWM = None, periodPWM = None, rgb_values = None):
    # Const
    intensitys = []
    rgbValues = []
    time = np.arange(0, stepLength, framerate)  

    if waveType == 'const':
        for i in range(int(stepLength/framerate)):
            intensitys.append(wvMax)
    # Sine
    elif waveType == 'sin':
        a = (wvMax - wvMin) / 2
        b = 2 * np.pi / wvLen
        d = a + wvMin
        if wvStart == 'Low':
            c = - (wvLen/4)
        elif wvStart == 'High':
            c = (wvLen/4)
 
        intensitys = a * np.sin(b * (time + c)) + d
    # Tri
    elif waveType == 'tri':
        a = (wvMax - wvMin) / 2
        d = a + wvMin
        if wvStart == 'Low':
            c = - (wvLen/4)
        elif wvStart == 'High':
            c = (wvLen/4)
 
        intensitys = (4 * a/wvLen * abs(((time + c - wvLen/4) % wvLen) - wvLen/2) - a) + d   
    # Square / PWM
    elif waveType in {'sq', 'pwm'}:
        TimePeriod = periodPWM
        percent = dutyCyclePWM

        if waveType == 'sq':
            TimePeriod = wvLen
            percent = 0.5

        if wvStart == 'Low':
            #pwm = time % TimePeriod < TimePeriod * percent #too simple
            period_frames = round(TimePeriod / framerate)
            on_frames = round(period_frames * percent)

            frame_indices = np.arange(len(time))
            pwm = (frame_indices % period_frames) < on_frames

            for dp in pwm:
                if dp:
                    intensitys.append(0)
                else:
                    intensitys.append(wvMax)
        elif wvStart == 'High':
            #pwm = time % TimePeriod < TimePeriod * percent
            period_frames = round(TimePeriod / framerate)
            on_frames = round(period_frames * percent)
            
            frame_indices = np.arange(len(time))
            pwm = (frame_indices % period_frames) < on_frames
            for dp in pwm:
                if dp:
                    intensitys.append(wvMax)
                else:
                    intensitys.append(0)
    # Rise
    elif waveType == 'rise':
        diff = wvMax - wvMin
        dp = wvMin

        for i in range(len(time)):
            intensitys.append(dp)
            dp += diff/(len(time)-1)
    # Fall
    elif waveType == 'fall':
        diff = wvMax - wvMin
        dp = wvMax

        for i in range(len(time)):
            intensitys.append(dp)
            dp -= diff/(len(time)-1)

    # for i in range(len(intensitys)):
    #     rgb = ()
    #     if color == 'Red':
    #         rgb = (round(intensitys[i]), 0, 0)
    #     elif color == 'Green':
    #         rgb = (0, round(intensitys[i]), 0)
    #     elif color == 'Blue':
    #         rgb = (0, 0, round(intensitys[i]))
    #     elif color == 'Multicolor':
    #         rgb = (round(intensitys[i]), round(intensitys[i]), round(intensitys[i]))
    #     rgbValues.append(rgb)

    # return rgbValues

    for intensity in intensitys:
        if color == 'Red':
            rgb = (round(intensity), 0, 0)
        elif color == 'Green':
            rgb = (0, round(intensity), 0)
        elif color == 'Blue':
            rgb = (0, 0, round(intensity))
        elif color == 'Multicolor' and rgb_values is not None:
            red, green, blue = rgb_values

            rgb = (
                round(intensity * red / 255),
                round(intensity * green / 255),
                round(intensity * blue / 255)
            )
        else:
            rgb = (0, 0, 0)

        rgbValues.append(rgb)

    return rgbValues
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

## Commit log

2026-07-30 Adding Everything
    [24_well_plate_adapter.step, 24_well_plate_adapter.stl, 6_well_plate_adapter.step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]
2026-08-13 Added Edited CADs
    [BackPlate_ReImagined2.stl, Huidu_Holder2.stl, Stands_ReImagined.stl]
